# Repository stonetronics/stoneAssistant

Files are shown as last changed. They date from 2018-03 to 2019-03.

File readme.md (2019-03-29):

stoneAssistant

This repository contains (pcb, firmware, mechanical) design files for the stoneAssistant project.
The stoneAssistant is meant to be a home-entertainment device built around a raspberry pi.

Planned features:
 - Raspberry Pi 3
 - LCD Touch Screen (official Raspberry Pi Touch Screen)
 - 15W Stereo sound
 - 12V Supply
 - 3 USB Ports
 - Speech Commands
   - microphone preamp
 - Pushbuttons for optional control (Home button, Play/Pause, etc)
 - ATtiny
   - RGB LED for nice appearance
   - Shutdown and Power Control
   - Controlable Fan
   - Serial Commands
 - 3D-printed enclosure
 
The device is powered by a 230VAC/12VDC switching supply and another 12VDC/5VDC DC/DC converter that powers the Raspberry Pi, ATtiny and USB Ports.
For power control (5V on Raspberry Pi, Software controlable mains switch), fan control and the RGB LEDs an ATtiny2312 chip is used. The chip implements a serial command interface on the uart to talk to the Raspberry Pi and vice versa.
The software (RingoWare) for touch screen control, media, etc is currently developed by https://github.com/Ringo96 and there will be a repo by him soon.
All the mechanical design files are drawn in FreeCAD 0.16. All the screw holes are designed to work with M3 screws. The PCBs sitting on top of the raspberry pi are meant to be held in place by standard M3 PCB spacers.

Files:

PCB files (Eagle 8)
- /PCBs/stoneAssistant_pwrMgmt.sch Power management and pwm schematic
- /PCBs/stoneAssistant_pwrMgmt.brd Power management and pwm board

Firmware files (Atmel Studio 7)
- /ATtinyFirmware/stoneAssistantController		Atmel Studio Solution for the ATtiny on the pwrMgmt board
 
Mechanical files (FreeCAD 0.16)
- /Mechanical/buttonPrototype    Prototype for Button with stopper
- /Mechanical/Frontplate         Frontplate that holds the raspberry pi display, buttons and speakers - prototype, did not fit in 3d printer
- /Mechanical/RPIMount           Mounting that holds the raspberry pi + PCBs on the raspberry pi display
- /Mechanical/Housing			 Model of the housing
!!!!!Moved all mechanical files to thingiverse

Serial Command Interface:

The serial command interface is using the uart and is based on a simple protocol, described below:

1 packet:
[Startbyte(0xaa)][Length][payload 0][payload 1] ... payload[length - 1][Stopbyte(0x55)]

In the payload of this protocol, the commands are transmitted. The following commands are implemented:
- [R][x] set red led intensity to x (0-255) (rpi->attiny)
- [G][x] set green led intensity to x (0-255) (rpi->attiny)
- [B][x] set blue led intensity to x (0-255) (rpi->attiny)
- [F][x] set fan speed to x (0-255) (rpi->attiny)
- [C][0] shutdown in 15s (rpi->attiny)
- [C][1] shutdown request (attiny->rpi)
- [C][6] cut rpi power and turn it on again in 15s (rpi->attiny)
- [C][9] hard reset rpi immediately (rpi->attiny)
- [C][10] hard shutdown immediately (rpi->attiny)

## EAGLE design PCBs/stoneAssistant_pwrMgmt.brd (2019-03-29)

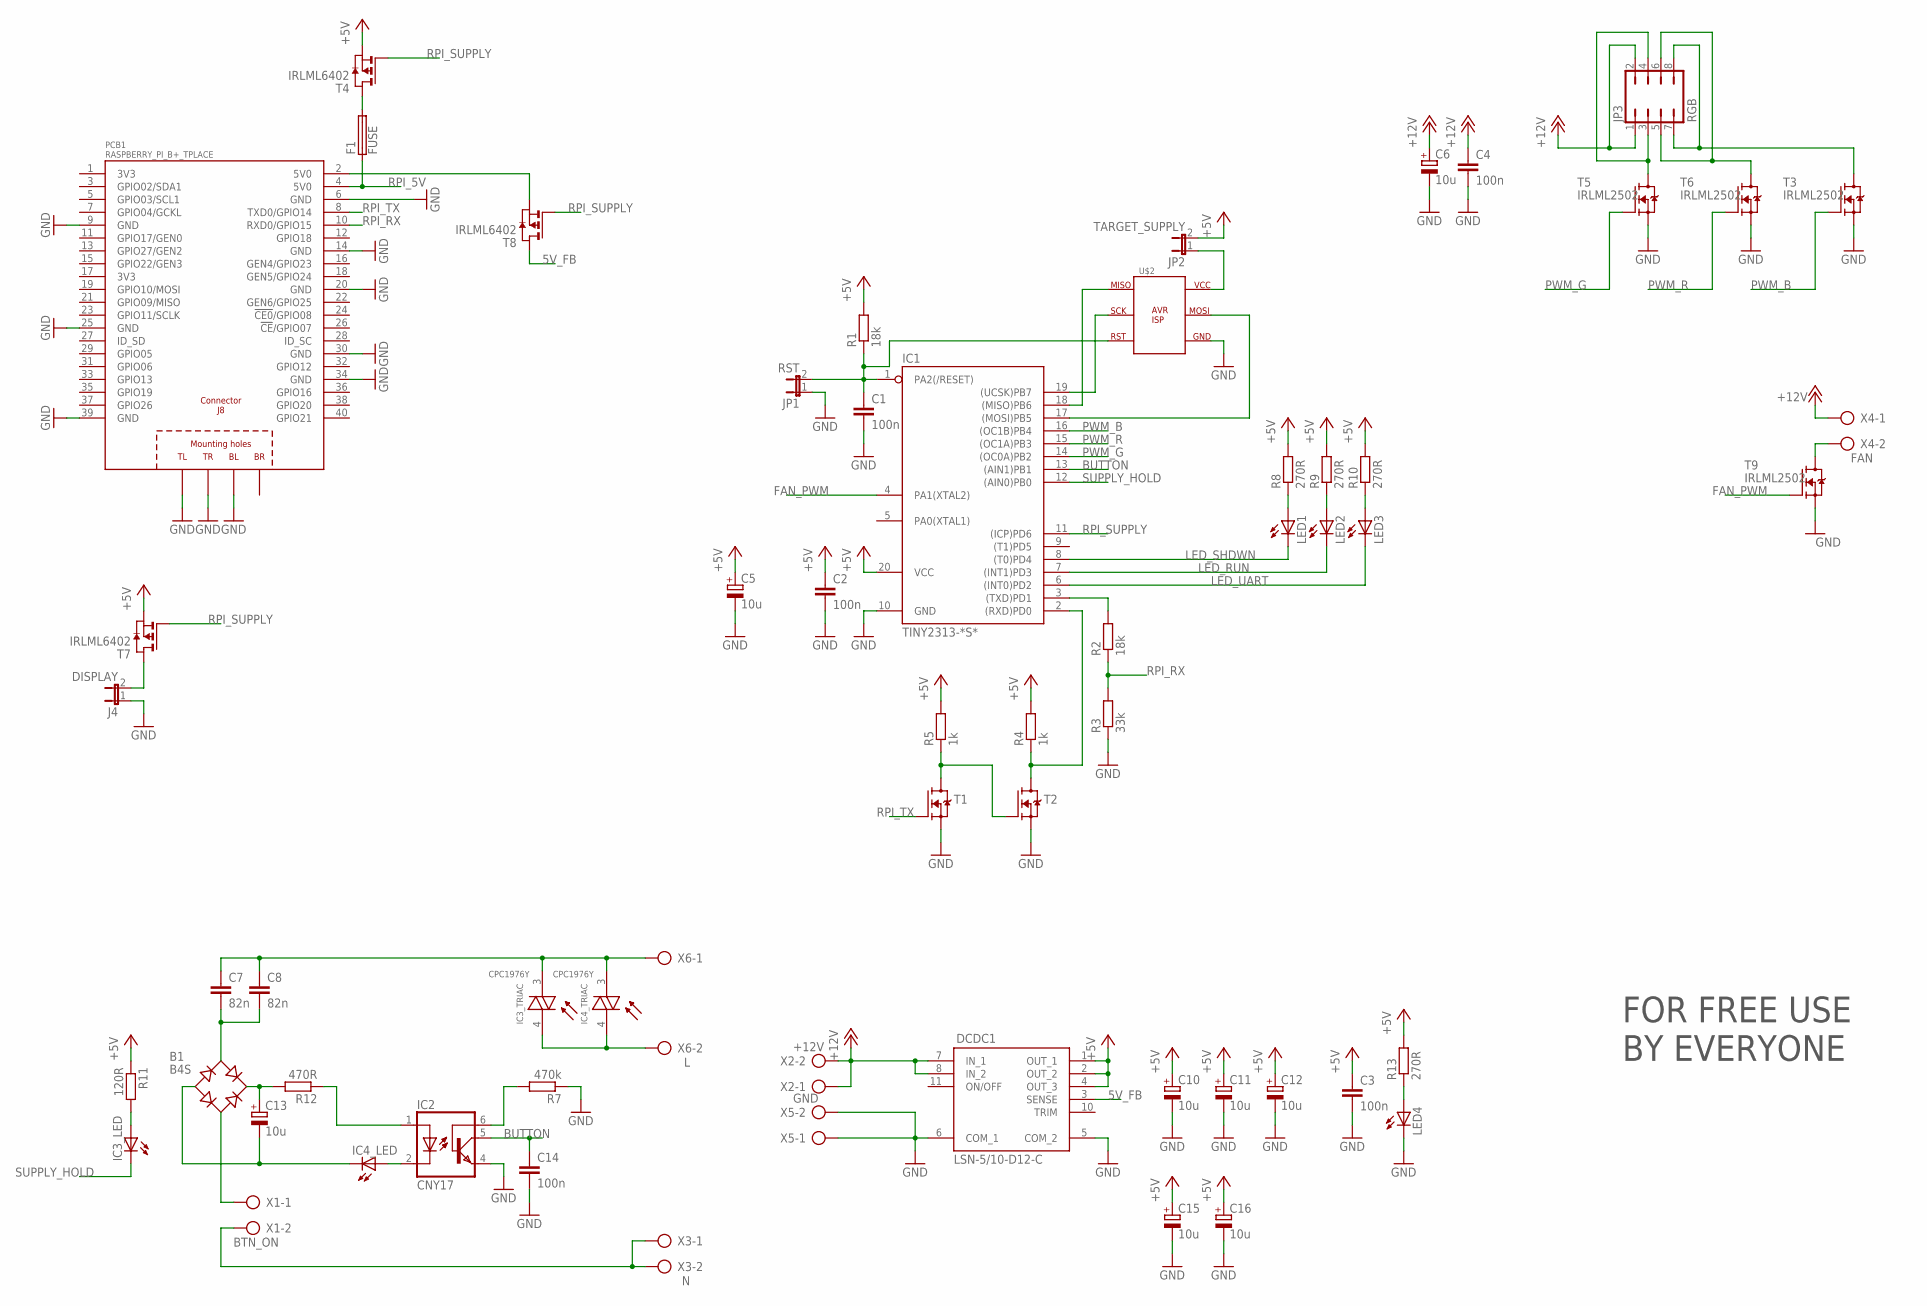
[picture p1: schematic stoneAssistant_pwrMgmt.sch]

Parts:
B1: B4S; MBS
C1, C2, C3, C4, C14: 100n; C0805
C5, C6, C10, C11, C12, C13, C15, C16: 10u; SMC_A
C7, C8: 82n; C050-075X075
DCDC1: LSN-5/10-D12-C; MURATA_LSN-5/10-D12-C
F1: FUSE; MF-SMDF050
IC1: TINY2313-*S*; SO20L$
IC2: CNY17; DIL06
IC3, IC4: CPC1976Y; SIP8/4
J4: DISPLAY; JP1
JP1: RST; JP1
JP2: TARGET_SUPPLY; JP1
JP3: RGB; JP4Q
LED1, LED2, LED3, LED4: LEDCHIPLED_0805; CHIPLED_0805
PCB1: RASPBERRY_PI_B+_TPLACE; RASPBERRY_PI_BPLUS_TPLACE
R1, R2: 18k; M0805
R3: 33k; M0805
R4, R5: 1k; M0805
R7: 470k; M0805
R8, R9, R10, R13: 270R; M0805
R11: 120R; M0805
R12: 470R; M0805
T1, T2: MOSFET-N-SOT23; SOT23
T3, T5, T6, T9: IRLML2502; SOT-23
T4, T7, T8: IRLML6402; SOT-23
U$2: AVR_ISPSINGLESIDED_SMD; PINHEADER_254_2X3_SMD
X1: BTN_ON; 2_2.54MM
X2: +12V; 2_2.54MM
X3: N; 2_2.54MM
X4: FAN; 2_2.54MM
X5: GND; 2_2.54MM
X6: L; 2_2.54MM

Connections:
3V3: PCB1.1 (3V3), PCB1.17 (3V3)
5V_FB: DCDC1.3 (SENSE), T8.3 (D)
+5V: C2.1, C3.1, C5.+, C10.+, C11.+, C12.+, C15.+, C16.+, DCDC1.1 (OUT_1), DCDC1.2 (OUT_2), DCDC1.4 (OUT_3), IC1.20 (VCC), JP2.2, R1.2, R4.2, R5.2, R8.2, R9.2, R10.2, R11.1, R13.2, T4.2 (S), T7.2 (S)
+12V: C4.1, C6.+, DCDC1.7 (IN_1), DCDC1.8 (IN_2), JP3.1, JP3.2, X2.1, X2.2, X4.1
BUTTON: C14.1, IC1.13 ((AIN1)PB1), IC2.5 (COL)
FAN_PWM: IC1.4 (PA1(XTAL2)), T9.1 (G)
GND: C1.2, C2.2, C3.2, C4.2, C5.-, C6.-, C10.-, C11.-, C12.-, C14.2, C15.-, C16.-, DCDC1.5 (COM_2), DCDC1.6 (COM_1), IC1.10 (GND), IC2.4 (EMI), J4.1, JP1.1, LED4.C, PCB1.6 (GND), PCB1.9 (GND), PCB1.14 (GND), PCB1.20 (GND), PCB1.25 (GND), PCB1.30 (GND), PCB1.34 (GND), PCB1.39 (GND), PCB1.PE_BL (BL), PCB1.PE_TL (TL), PCB1.PE_TR (TR), R3.1, R7.1, T1.2 (S), T2.2 (S), T3.2 (S), T5.2 (S), T6.2 (S), T9.2 (S), U$2.P$6 (GND), X5.1, X5.2
LED_RUN: IC1.7 ((INT1)PD3), LED2.C
LED_SHDWN: IC1.8 ((T0)PD4), LED1.C
LED_UART: IC1.6 ((INT0)PD2), LED3.C
unnamed: C1.1, IC1.1 (PA2(/RESET)), JP1.2, R1.1, U$2.P$3 (RST)
unnamed: IC1.3 ((TXD)PD1), R2.2
unnamed: IC1.2 ((RXD)PD0), R4.1, T2.3 (D)
unnamed: R5.1, T1.3 (D), T2.1 (G)
unnamed: IC2.2 (C), IC4.2 (A)
unnamed: IC1.19 ((UCSK)PB7), U$2.P$2 (SCK)
unnamed: IC1.18 ((MISO)PB6), U$2.P$1 (MISO)
unnamed: IC1.17 ((MOSI)PB5), U$2.P$7 (MOSI)
unnamed: JP2.1, U$2.P$8 (VCC)
unnamed: IC3.4 (A/C2), IC4.4 (A/C2), X6.2
unnamed: C7.1, C8.1, IC3.3 (A/C1), IC4.3 (A/C1), X6.1
unnamed: X1.2, X3.1, X3.2
unnamed: B1.AC1, C7.2, C8.2
unnamed: B1.-, C13.-, IC4.1 (C)
unnamed: B1.+, C13.+, R12.2
unnamed: B1.AC2, X1.1
unnamed: IC2.1 (A), R12.1
unnamed: IC2.6 (BAS), R7.2
unnamed: F1.2, T4.3 (D)
unnamed: LED4.A, R13.1
unnamed: JP3.3, JP3.4, T5.3 (D)
unnamed: JP3.5, JP3.6, T6.3 (D)
unnamed: JP3.7, JP3.8, T3.3 (D)
unnamed: J4.2, T7.3 (D)
unnamed: T9.3 (D), X4.2
unnamed: IC3.2 (A), R11.2
unnamed: PCB1.2 (5V0), T8.2 (S)
unnamed: LED1.A, R8.1
unnamed: LED2.A, R9.1
unnamed: LED3.A, R10.1
PWM_B: IC1.16 ((OC1B)PB4), T3.1 (G)
PWM_G: IC1.14 ((OC0A)PB2), T5.1 (G)
PWM_R: IC1.15 ((OC1A)PB3), T6.1 (G)
RPI_5V: F1.1, PCB1.4 (5V0)
RPI_RX: PCB1.10 (RXD0/GPIO15), R2.1, R3.2
RPI_SUPPLY: IC1.11 ((ICP)PD6), T4.1 (G), T7.1 (G), T8.1 (G)
RPI_TX: PCB1.8 (TXD0/GPIO14), T1.1 (G)
SUPPLY_HOLD: IC1.12 ((AIN0)PB0), IC3.1 (C)

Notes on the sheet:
FOR FREE USE BY EVERYONE

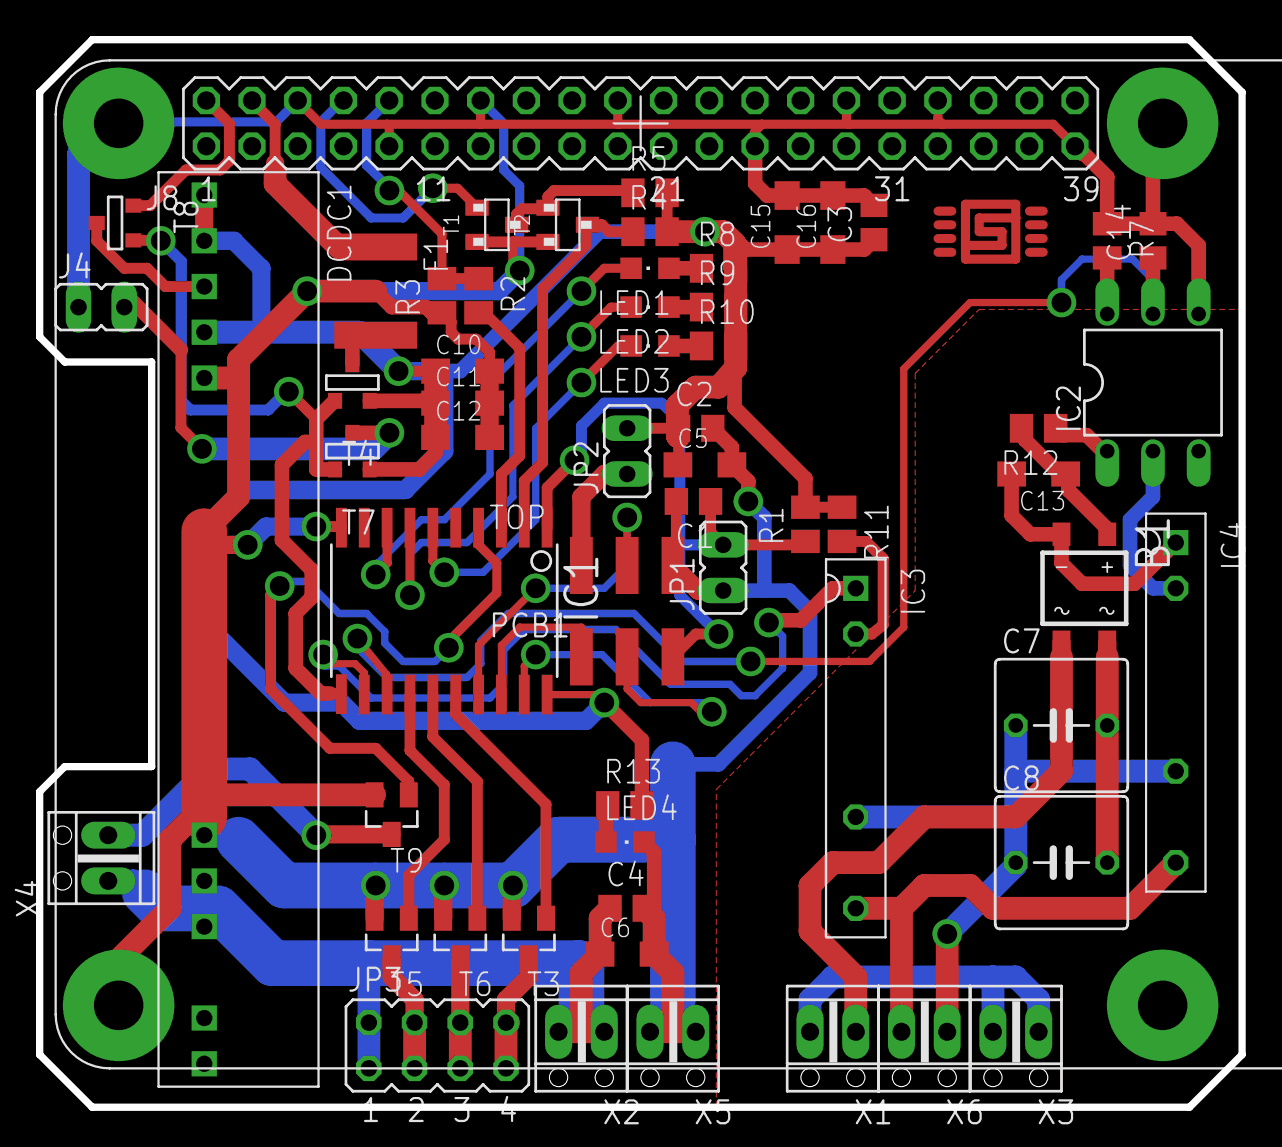
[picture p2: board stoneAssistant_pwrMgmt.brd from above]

Board: 2 copper layers, 66.8 x 59.3 mm, 59 parts (0 on the bottom side), 48 nets.

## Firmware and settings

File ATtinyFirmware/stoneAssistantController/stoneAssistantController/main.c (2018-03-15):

/*
 * stoneAssistantController.c
 *
 * Created: 05.03.2018 16:05:19
 * Author : Stone
 */ 

#define F_CPU  8000000UL

#include <avr/io.h>
#include <avr/interrupt.h>
#include <util/delay.h>
#include <stdlib.h>


#include "rgbPwmTimerFan.h"
#include "uart.h"
#include "stoneProtocol.h"

//time in seconds to give the rpi to shutdown
#define RPI_SHUTDOWN_SECONDS	15

//time in seconds for button press to send soft shutdown request
#define RPI_SHUTDOWN_REQ_TIME	2

//time in seconds for button press to trigger hard shutdown
#define RPI_SHUTDOWN_HARD_TIME	10


#define DDR_LED		DDRD
#define PORT_LED	PORTD
#define LED_SHDWN   PD4
#define LED_RUN		PD3
#define LED_UART    PD2

#define DDR_HOLD	DDRB
#define PORT_HOLD	PORTB
#define PIN_HOLD	PB0

#define DDR_BUTTON	DDRB
#define PORT_BUTTON PORTB
#define PIN_BUTTON	PINB
#define BUTTON		PB1

#define DDR_RPISUP	DDRD
#define PORT_RPISUP	PORTD
#define RPISUP		PD6

void shutdown(uint8_t shutdownSeconds)
{
	uint8_t i = 0; //iteration variable

	PORT_LED &= ~(1<<LED_SHDWN);
	rgbPwm_setHexColor(0x00FF0000); //red light to indicate shutdown sequence has started

	for (i = 0; i < shutdownSeconds; i++)	//shutdown delay
		_delay_ms(1000);

	PORT_RPISUP |= 1<<RPISUP; //release raspberry pi power supply
	PORT_HOLD |= 1<<PIN_HOLD; //release mains power supply (turn off)
}

void rpiHardReset(uint8_t shutdownSeconds)
{
	uint8_t i = 0; //iteration variable

	rgbPwm_setHexColor(0x00fffb26); //yellow light to indicate hard reset sequence has started

	for (i = 0; i < shutdownSeconds; i++)	//shutdown delay
		_delay_ms(1000);

	PORT_RPISUP |= 1<<RPISUP; //release raspberry pi power supply
	_delay_ms(500); //wait half a second to let the pi "cool down"
	PORT_RPISUP &= ~(1<<RPISUP); //turn on rpi power supply

	rgbPwm_setHexColor(0x00fffb26); //green light to indicate hard reset sequence has completed, rpi is on power again
}

void shutdownRequest()
{
	uint8_t requestMessage[2];

	requestMessage[0] = 'C';	//control message
	requestMessage[1] = 1;		//shutdown request

	stoneProtocol_transmit(requestMessage, 2);
}

int main(void)
{
	uint8_t inputChar = 0;
	uint8_t* payload = NULL;
	uint8_t protocolRet = 0;

	uint8_t button = 0;
	uint8_t buttonOld = 0;

	//init supply holding circuit (turned on)
	DDR_HOLD |= 1<<PIN_HOLD;
	PORT_HOLD &= ~(1<<PIN_HOLD);

	//init raspberry pi power control (turned on)
	DDR_RPISUP |= 1<<RPISUP;
	PORT_RPISUP &= ~(1<<RPISUP);

	//init button input with internal pull up enabled
	DDR_BUTTON &= ~(1<<BUTTON);
	PORT_BUTTON |= 1<<BUTTON;
	button = PIN_BUTTON & (1<<BUTTON);
	buttonOld = button;

	//init rgb and fan pwm timers (color: indigo, fan: 50%)
	rgbPwmTimerFan_init();
	rgbPwm_setHexColor(0);//x00b522f9);
	fan_setSpeed(127);

	//init leds
	DDR_LED  |= (1<<LED_SHDWN) | (1<<LED_RUN) | (1<<LED_UART);
	PORT_LED |= (1<<LED_SHDWN) | (1<<LED_RUN) | (1<<LED_UART);
	
	//init uart
	uart_init(9600,1,1);
	//init serial protocol
	stoneProtocol_init();

	//enable interrupts (needed for timer stuff)
	sei();

    while (1) 
    {
		//alive indication
		PORT_LED ^= (1<<LED_RUN);

		//button press handling
		button = PIN_BUTTON & (1<<BUTTON);
		if (buttonOld != button)
		{
			buttonOld = button;
			if (!button) //falling edge
			{
				timer_start();
			}
			else //rising edge
			{
				timer_stop();
			}
		}

		//button timer handling for shutdown
		if (timer_getTime() >= RPI_SHUTDOWN_REQ_TIME)
		{
			shutdownRequest();
		}
		if (timer_getTime() >= RPI_SHUTDOWN_HARD_TIME)
		{
			shutdown(1);
		}

		//usart protocol handling, command execution
		if (uart_testAndGetC(&inputChar))
		{
			PORT_LED ^= (1<<LED_UART);

			protocolRet = (stoneProtocol_loop(inputChar));
			switch (protocolRet)
			{
				case 0: //no new packet
				break;

				case 1: //new packet received
					payload = stoneProtocol_getMessage();
					if (payload != NULL)
					{
						switch (payload[0])
						{
							case 'r': //red led pwm - tested
							case 'R':
								rgbPwm_setR(payload[1]);
							break;

							case 'g': //green led pwm - tested
							case 'G':
								rgbPwm_setG(payload[1]);
							break;

							case 'b': //blue led pwm - tested
							case 'B':
								rgbPwm_setB(payload[1]);
							break;

							case 'x': //hexcode color - tested
							case 'X':
								rgbPwm_setHexColor(((uint32_t)payload[1]<<16) | ((uint32_t)payload[2]<<8) | ((uint32_t)payload[3])); //0x00RRGGBB
							break;

							case 'f': //fan pwm - tested
							case 'F':
								fan_setSpeed(payload[1]);
							break;

							case 'c': //command
							case 'C':

								switch (payload[1])
								{
									case 0: //shutdown
										shutdown(RPI_SHUTDOWN_SECONDS);
									break;

									//case 1: //shutdown request - nothing to do on attiny, just here for protocol doc
									//break;

									case 6: //reboot
										rpiHardReset(RPI_SHUTDOWN_SECONDS);
									break;

									case 9: //hard reset
										rpiHardReset(0);
									break;

									case 10: //hard shutdown
										shutdown(0);
									break;

									default:
									break;
								}
							break;

							default:
							break;
						}
						free(payload);
					}
				break;

				case 2: //protocol error
					PORT_LED |= 1<<LED_UART;
				break;
			}
		}
    }
}

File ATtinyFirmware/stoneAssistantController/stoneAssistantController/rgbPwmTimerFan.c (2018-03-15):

/*
 * rgbPwm.c
 *
 * Created: 05.03.2018 16:06:15
 *  Author: Stone
 */ 

 #include <avr/io.h>
 #include <avr/interrupt.h>
 #include "rgbPwmTimerFan.h"


 #define DDR_PWM	DDRB
 #define PORT_PWM	PORTB
 #define PIN_PWMB	PB4
 #define PIN_PWMR	PB3
 #define PIN_PWMG	PB2

 #define DDR_FAN		DDRA
 #define PORT_FAN	PORTA
 #define PIN_FAN		PINA
 #define FAN_PWM		PA1
 #define FAN_SIGNAL	PA0

 volatile uint8_t timerRunning;
 volatile uint16_t hundretMsCounter;
 volatile uint16_t overflowCounter;
 volatile uint8_t overflowFlag;

 void rgbPwmTimerFan_init() {
	timerRunning = 0;
	hundretMsCounter = 0;
	overflowCounter = 0;
	overflowFlag = 0;

	//init rgb pwm channel output pins (turned off)
	DDR_PWM |= (1<<PIN_PWMR) | (1<<PIN_PWMG) | (1<<PIN_PWMB);
	PORT_PWM &= ~((1<<PIN_PWMR) | (1<<PIN_PWMG) | (1<<PIN_PWMB));

	//init fan control pins (fan turned off)
	DDR_FAN |= 1<<FAN_PWM;
	PORT_FAN &= ~(1<<FAN_PWM);
	DDR_FAN &= ~(1<<FAN_SIGNAL);
	//PORT_FAN |= (1<<FAN_SIGNAL);

	//timer 0 initialization G - OC0A; interrupt used for Fan - OCR0B; also used for 100ms increment
	TCCR0A |= (2<<COM0A0) | (3<<WGM00); //Fast PWM mode with oc0a = 1 at TCNT0 < OCR0A
	TCCR0B |= (4<<CS00); //start timer with clk/256 = 31.25kHz
	TIMSK |= (1<<OCIE0B) | (1<<TOIE0); //enable interrupts for ocr0b and overflow
	TCNT0 = 0;
	OCR0A = 0;
	OCR0B = 0;

	//timer 1 initialization R - OC1A; B - OC1B;
	TCCR1A |= (2<<COM1A0) | (2<<COM1B0) | (1<<WGM10); //8-Bit Fast PWM with oc1a and oc1b pwm operation
	TCCR1B |= (1<<WGM12) | (4<<CS10); //start timer with clk/256 = 31.25kHz
	TCNT1H = 0;
	TCNT1L = 0;
	OCR1AH = 0;
	OCR1AL = 0;
	OCR1BH = 0;
	OCR1BL = 0;
 }

 void rgbPwm_setR(uint8_t r)
 {
	OCR1AL = r;
 }

 void rgbPwm_setG(uint8_t g)
 {
	OCR0A = g;
 }

 void rgbPwm_setB(uint8_t b)
 {
	OCR1BL = b;
 }

 void rgbPwm_setHexColor(uint32_t hexCode)
 {
	rgbPwm_setR((hexCode & 0x00FF0000)>>16);
	rgbPwm_setG((hexCode & 0x0000FF00)>>8);
	rgbPwm_setB((hexCode & 0x000000FF));
 }

 void fan_setSpeed(uint8_t f)
 {
	OCR0B = f;
 }

 void timer_start()
 {
	uint8_t temp_SREG = 0;

	temp_SREG = SREG;

	cli();

	hundretMsCounter = 0;
	overflowCounter = 0;
	overflowFlag = 0;
	timerRunning = 1;

	SREG = temp_SREG;
 }

 void timer_stop()
 {
	timerRunning = 0;
 }

 uint8_t timer_overflow()
 {
	return overflowFlag;
 }

 uint16_t timer_getTime()
 {
	return hundretMsCounter;
 }

 ISR(TIMER0_COMPB_vect)
 {
	PORT_FAN &= ~(1<<FAN_PWM); //set fan pin low at end of pulse
 }

 ISR(TIMER0_OVF_vect)
 {
	PORT_FAN |= (1<<FAN_PWM); //set fan pin high at start of pulse

	if (timerRunning) //increment timer if enabled
	{
		//counter for 1s
		if ((overflowCounter++) == 122) //999,424ms
		{
			overflowCounter = 0;

			//100ms chunks counter
			if ((hundretMsCounter++) == 0xFFFF)
			{
				hundretMsCounter = 0;
				overflowFlag = 1;
			}
		}
	}
 }

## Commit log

2018-02-21 first prototype for buttons with stopper mechanism included
    [button.stl, buttonHolder.FCStd, frontplatte.stl]
2018-02-22 lower profile design converted stoppers into linear translation guides adjusted stoppers and pcb mount to 2.54 grid for easier assembly with protoboard strengthening against bending in the front plate
    [button.stl, buttonHolder.FCStd, buttonPrototype.FCStd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]
2018-02-26 Added PCB for power management and pwm Added First Frontplate design with three buttons, display, 2 speakers and usb soundcard pcb holder - seems to be too big for 3d printer, i might redo this so it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
    [Frontplate.FCStd, button.FCStd, buttonPrototype.FCStd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]
2018-03-12 updated frontplate design -> too big for 3d printer partial case design with tilted speakers button update Raspberry Pi Mounting frame
    [Frontplate.FCStd, Housing.FCStd, RPIMount.FCStd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]
2018-03-13 mechanical: added first housing design - now fits into printing space
    [Housing.FCStd]
2018-03-13 electrical: pcb redesign for better fit of components, transistor level shifter moved away from dc/dc, smd rectifier instead of tht one, cancelled out snubber, isp moved away from edge so the attiny 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
    [stoneAssistant_pwrMgmt.brd, stoneAssistant_pwrMgmt.sch]
2018-03-13 firmware: initial firmware commit, includes uart receive protocol handling (tx not tested yet!), pwm on rgb leds, fan pwm still missing, first shutdown functionality
    [main.c, stoneProtocol.c, uart.c]
2018-03-15 added fan control and button handling (hard-/soft-shutdown) to the firmware update readme.md
2018-06-14 final power management pcb
    [stoneAssistant_pwrMgmt.brd, stoneAssistant_pwrMgmt.sch]
2019-03-29 move mechanical to thingiverse
    [Frontplate.FCStd, Housing.FCStd, RPIMount.FCStd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]
